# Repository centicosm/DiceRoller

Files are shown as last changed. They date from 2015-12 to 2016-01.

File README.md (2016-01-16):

# Yet Another Dice Roller
Dual 7-segment LED PIC uC dice rolling toy with schematic. pcb, and 3d-printable case

Selectable dice types: 1d2, 2d2, 1d4, 2d4, 1d6, 2d6, 1d8, 2d8, 1d10, 1d12, 1d100, 1d20.<br>
Display will auto-shutoff after around 10s

MPLab X with XC8 toolchain used.

For the uC used (a PIC 16F88) after programming the chip the first time, Vpp first programming mode must be used to reflash firmware as the internal oscillator is used along with all available pins (MCLR).

BOM
----------------------------------------------------------------
PIC 16F88 PDIP<br>
10K 1/4 Watt Resistor<br>
10 1/4 Watt Resistor<br>
.33uF Capacitor<br>
.1uF Capacitor<br>
2 NTE3078 7-Segment LED<br>
LM340T5 (TO-220)<br>
9V Battery connector<br>
6.2mm cutout pushbutton switch (e.g. GPB024A05BB)<br>
12mm cutout pushbutton switch<br>
15mm Panel mount SPDT On-Off Switch (e.g. EG1201)

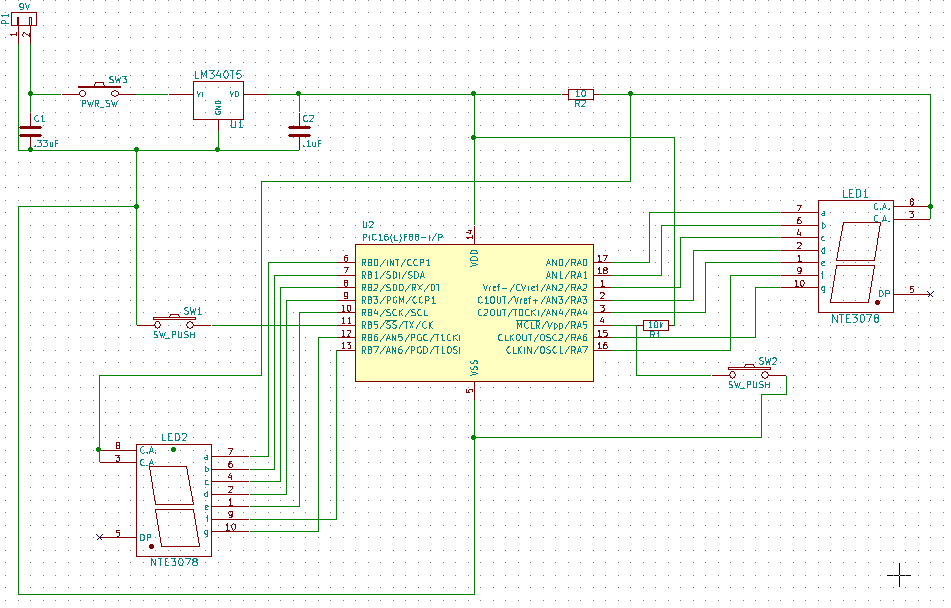
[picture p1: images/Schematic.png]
Schematic

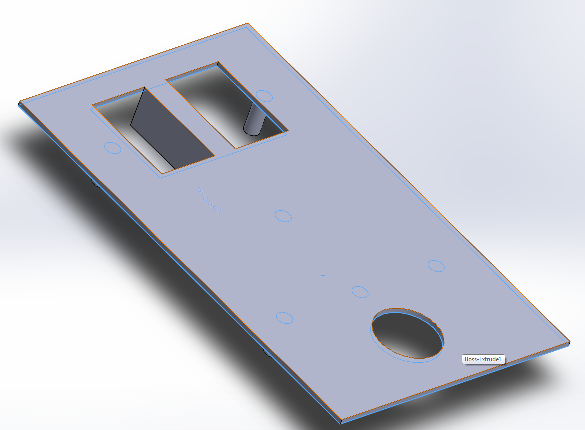
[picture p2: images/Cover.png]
Cover

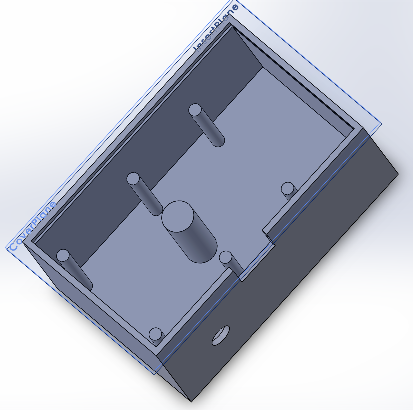
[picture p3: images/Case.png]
Case


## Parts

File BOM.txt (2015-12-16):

PIC 16F88 PDIP
10K 1/4 Watt Resistor
10 1/4 Watt Resistor
.33uF Capacitor
.1uF Capacitor
2 NTE3078 7-Segment LED
LM340T5 (TO-220)
9V Battery connector
6.2mm cutout pushbutton switch (e.g. GPB024A05BB)
12mm cutout pushbutton switch
15mm Panel mount SPDT On-Off Switch (e.g. EG1201)

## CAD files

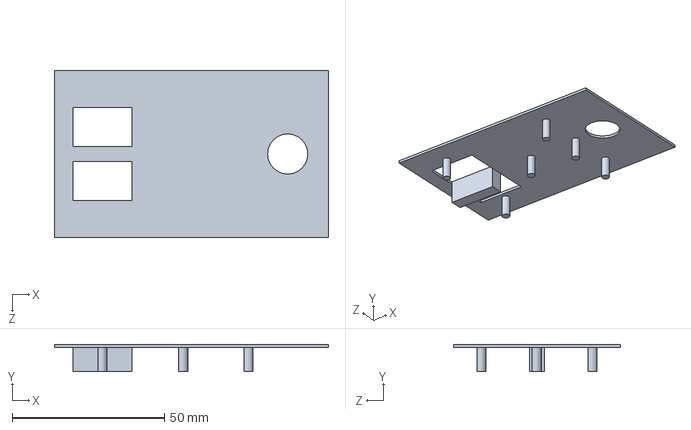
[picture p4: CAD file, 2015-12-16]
Case/CaseCover.SLDPRT
90.0 x 9.00 x 55.0 mm

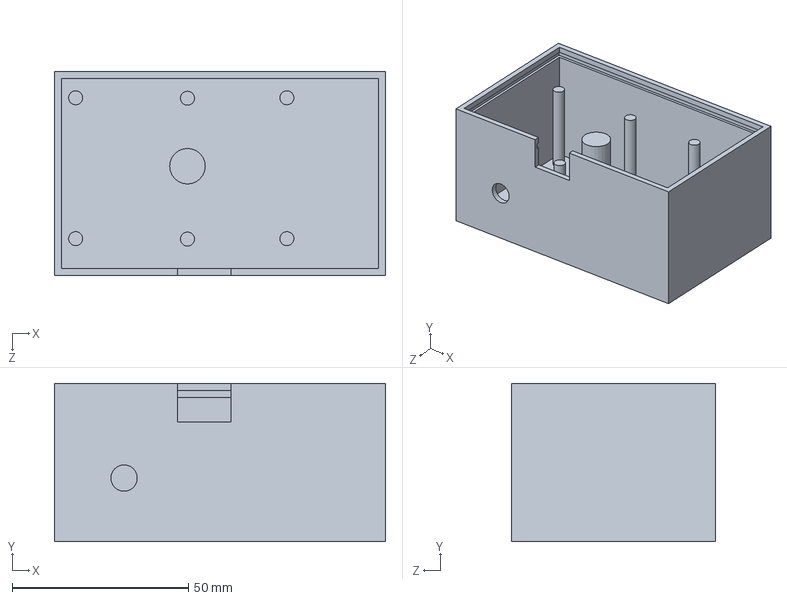
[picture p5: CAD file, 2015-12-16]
Case/CaseBottom.SLDPRT
94.0 x 45.0 x 58.0 mm

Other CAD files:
Case/CaseBottom.STL
Case/CaseCover.STL

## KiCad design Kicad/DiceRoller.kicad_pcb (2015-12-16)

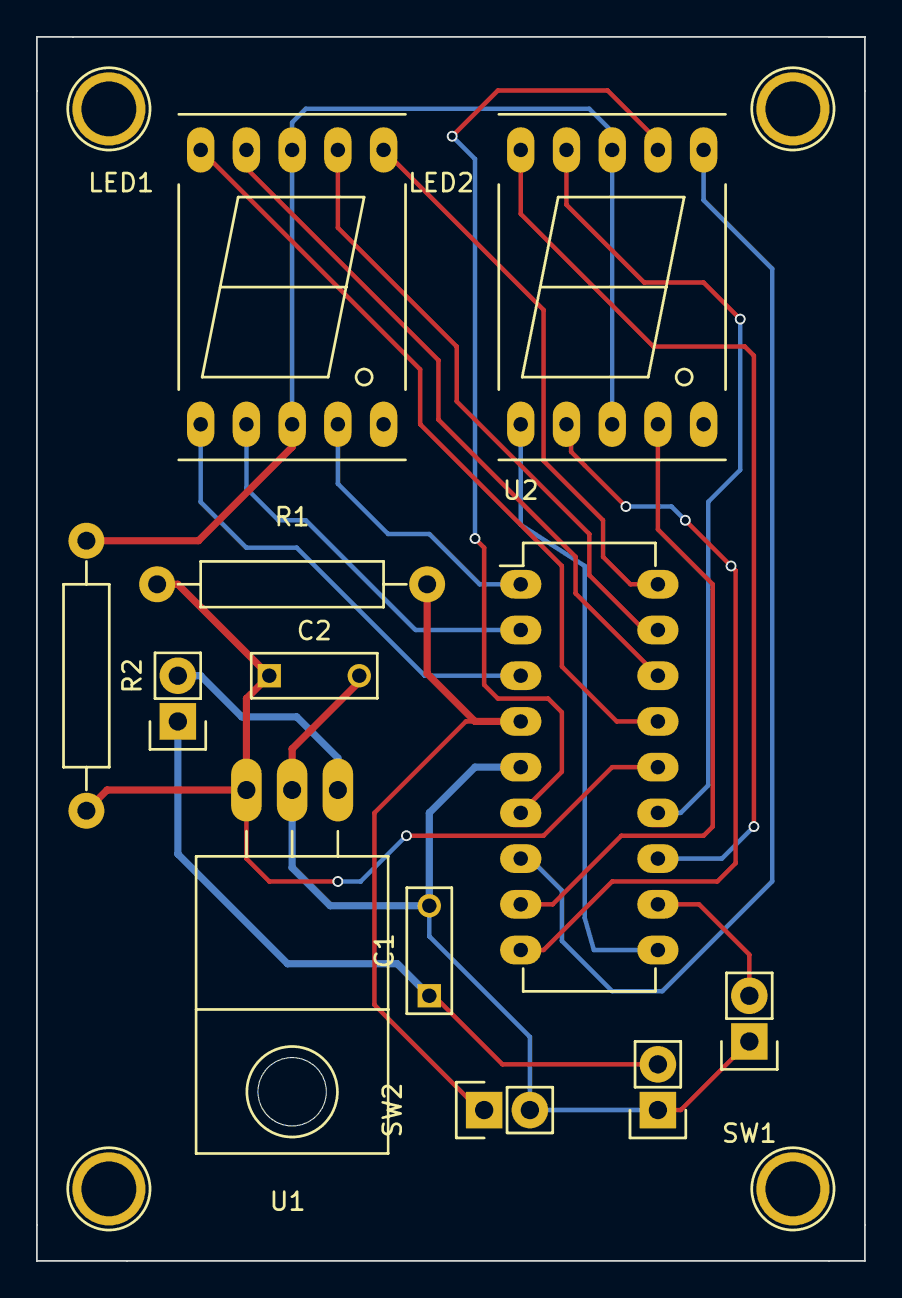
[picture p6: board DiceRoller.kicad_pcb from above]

Board: 2 copper layers, 46.0 x 68.0 mm, 10 parts (0 on the bottom side), 19 nets.

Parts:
C1: .33uF; C_Rect_L7_W2.5_P5
C2: .1; C_Rect_L7_W2.5_P5
LED1, LED2: NTE3078; 7SegmentLED_LTS6760_LTS6780
R1: 10k; Resistor_Horizontal_RM15mm
R2: 10; Resistor_Horizontal_RM15mm
SW1, SW2: SW_PUSH; Pin_Header_Straight_1x02
U1: 7805; TO-220_Neutral123_Horizontal_LargePads
U2: PIC16(L)F88-I/P; DIP-18_W7.62mm_LongPads

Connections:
unnamed: C1.2, C2.2, SW1.1, SW2.2, U1.2, U2.5
unnamed: C2.1, R1.1, R2.2, U1.3, U2.14
unnamed: LED1.1, U2.3
unnamed: LED1.2, U2.2
unnamed: LED1.3, LED1.8, LED2.3, LED2.8, R2.1
unnamed: LED1.4, U2.1
unnamed: LED1.6, U2.18
unnamed: LED1.7, U2.17
unnamed: LED1.9, U2.16
unnamed: LED1.10, U2.15
unnamed: LED2.1, U2.10
unnamed: LED2.2, U2.9
unnamed: LED2.4, U2.8
unnamed: LED2.6, U2.7
unnamed: LED2.7, U2.6
unnamed: LED2.9, U2.13
unnamed: LED2.10, U2.12
unnamed: R1.2, SW2.1, U2.4
unnamed: SW1.2, U2.11

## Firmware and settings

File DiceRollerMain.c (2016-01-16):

/*
 * File:   DiceRollerMain.c
 * Author: centicosm
 */


#include <xc.h>
//#include <16F88.H>
#include <stdbool.h>
#include <stdint.h>
#include <stdlib.h>
#include "DiceRollerConfig.h"

enum DiceType {
    D2 = 0,
    D2D2,
    D4,
    D4D4,
    D6,
    D6D6,
    D8,
    D8D8,
    D10,
    D10D10,
    D12,
    D20,
    DICE_END
};

#define NO_DIE                  10

#define BUTTON_TYPE_BUTTON      0b00000001
#define BUTTON_ROLL_BUTTON      0b00000010


#define LED_A  0b00000001
#define LED_B  0b00000010
#define LED_C  0b00000100
#define LED_D  0b00001000
#define LED_E  0b00010000
#define LED_F  0b10000000
#define LED_G  0b01000000



enum DiceType _CurDiceType;
uint16_t _DebounceCntDiceType;
uint16_t _DebounceRollDice;
uint8_t _LastButtons;
uint8_t _TimeOutCnt = 0;



void Init_System(void) {
    OSCCON |= 0b01110000;
    
    __delay_ms(1000);
    ANSEL = 0x00;
    TRISA = 0x00;
    TRISB = 0x00;

    // the roll button and the switch dice button are inputs
    TRISAbits.TRISA5 = 1;
    TRISBbits.TRISB5 = 1;
    OPTION_REG &= 0b01111111;
    
    _CurDiceType = D6;
    
    // set up the timers for doing the random numbers
    T2CON = 0x00;
    T2CONbits.TMR2ON = 1;
    OPTION_REGbits.T0CS = 0;
    
    // and a timer for debouncing and screen deactivation
    T1CON = 0b00000001;  // Timer 1 is based on system clock and enabled
    PIR1bits.TMR1IF = 0;
    _DebounceCntDiceType = 0;
    _LastButtons = 0x00;
    
    uint16_t timer;
    timer = TMR1;
    srand((unsigned)timer);         
    
}


void Set_Led1(uint8_t val) {

    uint8_t outPort;
    switch (val) {

        case 0:
            outPort = (LED_A | LED_B | LED_C | LED_D | LED_E | LED_F);
            break;

        case 1:
            outPort = (LED_B | LED_C);
            break;

        case 2:
            outPort = (LED_A | LED_B | LED_G | LED_D | LED_E);
            break;

        case 3:
            outPort = (LED_A | LED_B | LED_C | LED_D | LED_G);
            break;

        case 4:
            outPort = (LED_F | LED_G | LED_B | LED_C);
            break;

        case 5:
            outPort = (LED_A | LED_F | LED_G | LED_C | LED_D);
            break;

        case 6:
            outPort = (LED_A | LED_C | LED_D | LED_E | LED_F | LED_G);
            break;

        case 7:
            outPort = (LED_A | LED_B | LED_C);
            break;

        case 8:
            outPort = (LED_A | LED_B | LED_C | LED_D | LED_E | LED_F | LED_G);
            break;

        case 9:
            outPort = (LED_A | LED_B | LED_C | LED_D | LED_F | LED_G);
            break;


        default:
            outPort = 0x00;
    }

    outPort = ~outPort;
    PORTA = outPort;
}

void Set_Led2(uint8_t val) {

    uint8_t outPort;
    switch (val) {

        case 0:
            outPort = (LED_A | LED_B | LED_C | LED_D | LED_E | LED_F);
            break;

        case 1:
            outPort = (LED_B | LED_C);
            break;

        case 2:
            outPort = (LED_A | LED_B | LED_G | LED_D | LED_E);
            break;

        case 3:
            outPort = (LED_A | LED_B | LED_C | LED_D | LED_G);
            break;

        case 4:
            outPort = (LED_F | LED_G | LED_B | LED_C);
            break;

        case 5:
            outPort = (LED_A | LED_F | LED_G | LED_C | LED_D);
            break;

        case 6:
            outPort = (LED_A | LED_C | LED_D | LED_E | LED_F | LED_G);
            break;

        case 7:
            outPort = (LED_A | LED_B | LED_C);
            break;

        case 8:
            outPort = (LED_A | LED_B | LED_C | LED_D | LED_E | LED_F | LED_G);
            break;

        case 9:
            outPort = (LED_A | LED_B | LED_C | LED_D | LED_F | LED_G);
            break;


        default:
            outPort = 0x00;
    }

    outPort = ~outPort;
    PORTB = outPort;
}

void Display_DiceType(void) {
    switch (_CurDiceType) {

        case D2:
            Set_Led2(2);
            Set_Led1(NO_DIE);
            break;

        case D2D2:
            Set_Led2(2);
            Set_Led1(2);
            break;

        case D4:
            Set_Led2(4);
            Set_Led1(NO_DIE);
            break;

        case D4D4:
            Set_Led2(4);
            Set_Led1(4);
            break;

        case D6:
            Set_Led2(6);
            Set_Led1(NO_DIE);
            break;

        case D6D6:
            Set_Led2(6);
            Set_Led1(6);
            break;

        case D8:
            Set_Led2(8);
            Set_Led1(NO_DIE);
            break;

        case D8D8:
            Set_Led2(8);
            Set_Led1(8);
            break;

        case D10:
            Set_Led2(0);
            Set_Led1(1);
            break;

        case D10D10:
            Set_Led2(9);
            Set_Led1(9);
            break;

        case D12:
            Set_Led2(2);
            Set_Led1(1);
            break;

        case D20:
            Set_Led2(0);
            Set_Led1(2);
            break;

        default:
            Set_Led1(NO_DIE);
            Set_Led2(NO_DIE);
            break;
    }
}

void Increment_DiceType(void) {
    ++_CurDiceType;
    if (_CurDiceType == DICE_END) {
        _CurDiceType = 0;
    }
    Display_DiceType();
    _TimeOutCnt = 0;
}


void Get_Dice1(uint8_t val) {
    
    uint8_t roll = rand() % val;
    Set_Led1(roll + 1);
}


void Get_Dice2(uint8_t val) {
    
    uint8_t roll = rand() % val;
    ++roll;
      
    uint8_t tens = 0;
    while(roll >= 10) {
        ++tens;
        roll -= 10;
    }
    
    if (tens == 10) {
        Set_Led2(0);
        Set_Led1(0);    
    }
    else {
        if (tens > 0) {
            Set_Led1(tens);
        }
        else {
            Set_Led1(10);
        }
        Set_Led2(roll);    
    }
    
}


void Roll_Dice(void) {
    switch (_CurDiceType) {

        case D2:
            Get_Dice2(2);
            Set_Led1(NO_DIE);
            break;

        case D2D2:
            Get_Dice2(2);
            Get_Dice1(2);
            break;

        case D4:
            Get_Dice2(4);
            Set_Led1(NO_DIE);
            break;

        case D4D4:
            Get_Dice2(4);
            Get_Dice1(4);
            break;

        case D6:
            Get_Dice2(6);
            Set_Led1(NO_DIE);
            break;

        case D6D6:
            Get_Dice2(6);
            Get_Dice1(6);
            break;

        case D8:
            Get_Dice2(8);
            Set_Led1(NO_DIE);
            break;

        case D8D8:
            Get_Dice2(8);
            Get_Dice1(8);
            break;

        case D10:
            Get_Dice2(10);
            break;

        case D10D10:
            Get_Dice2(100);
            break;

        case D12:
            Get_Dice2(12);
            break;

        case D20:
            Get_Dice2(20);
            break;

        default:
            Set_Led1(NO_DIE);
            Set_Led2(NO_DIE);
            break;
    }
    
    _TimeOutCnt = 0;
}


void Handle_Buttons(void) {
    
    uint8_t but = 0x00;
    
    // turn off the display after around 10 sec
    if (PIR1bits.TMR1IF == 0x01) {
        PIR1bits.TMR1IF = 0;
        if (_TimeOutCnt < 254) {
            _TimeOutCnt++;
            if (_TimeOutCnt >= 254) {
                Set_Led1(NO_DIE);
                Set_Led2(NO_DIE);
                
                // put the device to sleep to awake again on button press
                INTCONbits.RBIF = 0;
                INTCONbits.RBIE = 1;
                
                asm("sleep");
                asm("nop");
                                
                INTCONbits.RBIE = 0;
                
            }            
        }
    }
    
    //  The change dice type button was pressed
    if (PORTAbits.RA5) {
        if (0 == (_LastButtons & BUTTON_TYPE_BUTTON)) {
            _DebounceCntDiceType++;
            if (_DebounceCntDiceType == 1200) {
                _LastButtons |= BUTTON_TYPE_BUTTON;
                Increment_DiceType();
                uint16_t timer;
                timer = TMR1;
                srand((unsigned)timer); 
            }
        }
    }
    else {
        _DebounceCntDiceType = 0;
        _LastButtons &= ~BUTTON_TYPE_BUTTON;
    }
     
    // the roll dice button was pressed
    if (PORTBbits.RB5) { 
      //  if (0 == (_LastButtons & BUTTON_ROLL_BUTTON)) {
        //    _DebounceRollDice++;
//            if (_DebounceRollDice == 1200) {
  //              _LastButtons |= BUTTON_ROLL_BUTTON;    
    //            _DebounceRollDice = 0;
      //      }
        //}
        //else {
            Roll_Dice();
        //}
    }
    
    // roll not pressed
    else {
        
        // if it was pressed before debounce
        /*if ((_LastButtons & BUTTON_ROLL_BUTTON)) {
            _DebounceRollDice++;
            if (_DebounceRollDice == 1200) {
                _LastButtons &= ~BUTTON_ROLL_BUTTON;
                Roll_Dice();
                _DebounceRollDice = 0;
            }
        }
        else {
            _DebounceRollDice = 0;
        }*/
    }
}


void main(void) {

    Init_System();
    
    Display_DiceType();

    while (1) {
        Handle_Buttons();
    }

}

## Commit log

2015-12-16 PIC uController Electronic Dice
    Dual 7-segment LED PIC microcontroller-based dice rolling toy with KiCad
    schematic, pcb, and 3d-printable case
    [CaseBottom.SLDPRT, CaseBottom.STL, CaseCover.SLDPRT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]
2016-01-16 Swapped Buttons on MCU for adding sleep/wake capability
    [DiceRollerMain.c]
